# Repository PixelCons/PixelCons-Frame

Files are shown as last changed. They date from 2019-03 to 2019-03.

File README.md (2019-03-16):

# PixelCons-Frame
Pixel Art Showcase Frame

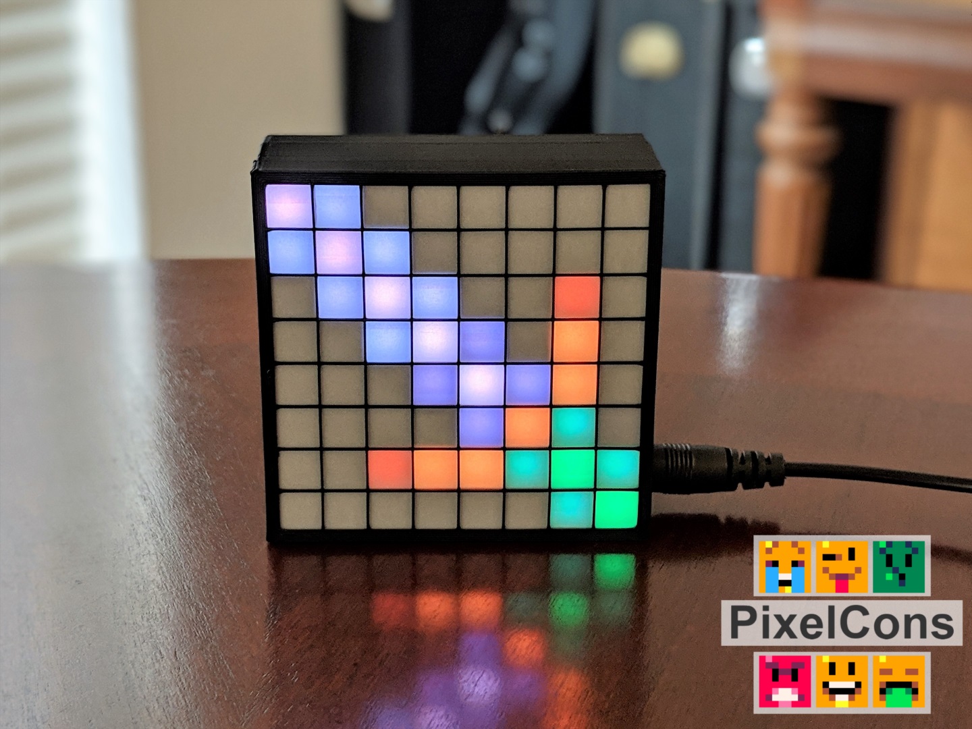
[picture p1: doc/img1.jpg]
Example


The PixelCon Frame is small device that displays pixel art (known as PixelCons) from the web. The pixel art is displayed on a bright 8x8 matrix of LEDs and is powered by the inexpensive WiFi enabled esp8266 board. Everything is enclosed in a 2.75in square 3D printed case.

Pixel art displayed on the frame comes from the PixelCon ecosystem on the Ethereum blockchain. Anyone can make and explore PixelCon and using the power of the Ethereum blockchain, each PixelCon can be owned, collected, and traded like a cryptocurrency.

Refer to the User Guide [here](https://github.com/PixelCons/PixelCons-Frame/blob/master/doc/PixelCon%20Frame%20(mini).pdf) for more information on using/setting up the PixelCon Frame once it's been assembled.

## Hardware
The PixelCon Frame consists of two main components, the NodeMCU ESP8266 microcontroller dev board and an 8x8 matrix of WS2812 LEDs. Other smaller passive components needed include an electrolytic capacitor, n-channel transistor and a single resistor.

- NodeMCU ESP8266 ([Amazon](https://www.amazon.com/NodeMCU-ESP8266-Internet-ESP-12E-Development/dp/B074Z2VL6S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))
- 8x8 WS2812 LEDs ([Amazon](https://www.amazon.com/Semoic-Matrix-WS2812-Full-Color-Arduino/dp/B07M6D5X34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))
- 5V 3A Power Supply ([Amazon](https://www.amazon.com/Bestcompu-Converter-Wireless-Switches-Video%EF%BC%885-5mm/dp/B00ME78NSS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))
- NPN Transistor
- DC Barrel Jack
- 8pin Female Headers (x2)
- 1000uF Capacitor
- 2.6kOhm Resistor

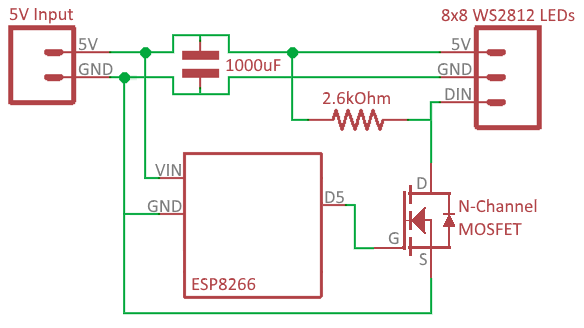
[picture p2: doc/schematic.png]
Schematic


## Software
All software for the PixelCon Frame is run on the ESP8266 microcontroller and was designed to use the Arduino IDE for flashing the code. To flash the code to the NodeMCU ESP8266 board, follow these steps:

1. Download and install the arduino IDE [here](https://www.arduino.cc/en/Main/Software).
2. Add the ESP8266 boards to the Arduino IDE by following this [tutorial](https://www.instructables.com/id/Programming-ESP8266-ESP-12E-NodeMCU-Using-Arduino-/).
3. Download the source code [here](https://codeload.github.com/PixelCons/PixelCons-Frame/zip/master) and unzip into a folder labeled ‘PixelCon-Frame’. 
4. Add the WiFi Manager library development branch to the Arduino IDE by downloading it [here](https://codeload.github.com/tzapu/WiFiManager/zip/development) and unzip into a folder labeled ‘WiFiManager’ in the directory ‘Documents\Arduino\libraries’. 
5. Open the PixelCons-Frame.ino file in the Arduino IDE and click the ‘Verify’ button to make sure everything compiles successfully. Refer back to the earlier tutorial [here](https://www.instructables.com/id/Programming-ESP8266-ESP-12E-NodeMCU-Using-Arduino-/) for uploading the code to the ESP8266 on the NodeMCU dev board.

Packed inside of the code is the web interface for configuring the behavior of the PixelCon Frame. Refer to the User Guide [here](https://github.com/PixelCons/PixelCons-Frame/blob/master/doc/PixelCon%20Frame%20(mini).pdf) for an explanation of using the software.

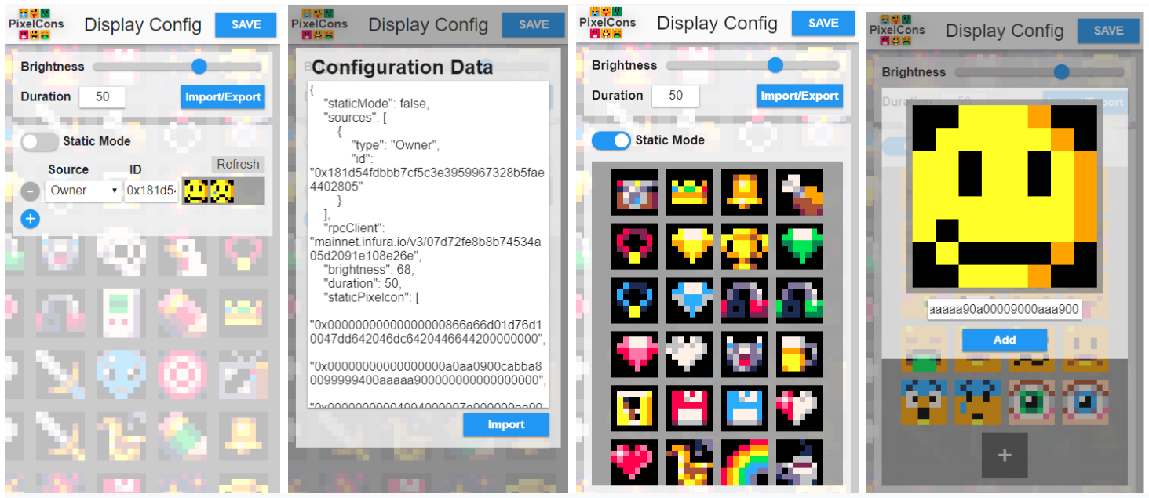
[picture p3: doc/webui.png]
WebUI


## Assembly
The PixelCon Frame body can be 3D printed from the STL files found [here](https://github.com/PixelCons/PixelCons-Frame/tree/master/stl) in the stl folder. To make your own, simply print them out and follow these assembly steps:

1. Place a cut piece of paper in between the 'frame' and the 'front' prints and snap in place.
2. The ESP8266 board should be screwed into into the 'backplate' with the 'buttons' in place. 
3. Super glue the 'bracket' onto the back of the LED matrix with all of the components in place. 
4. Wire and solder the correct components together according to the schematic.
5. Hot glue the LED matrix into the 'frame' so that the DC jack lines up with the hole in the 'frame'. 
6. Push the 'backplate' into place at the back of the 'frame', seating the ESP8266 pins into the female headers.

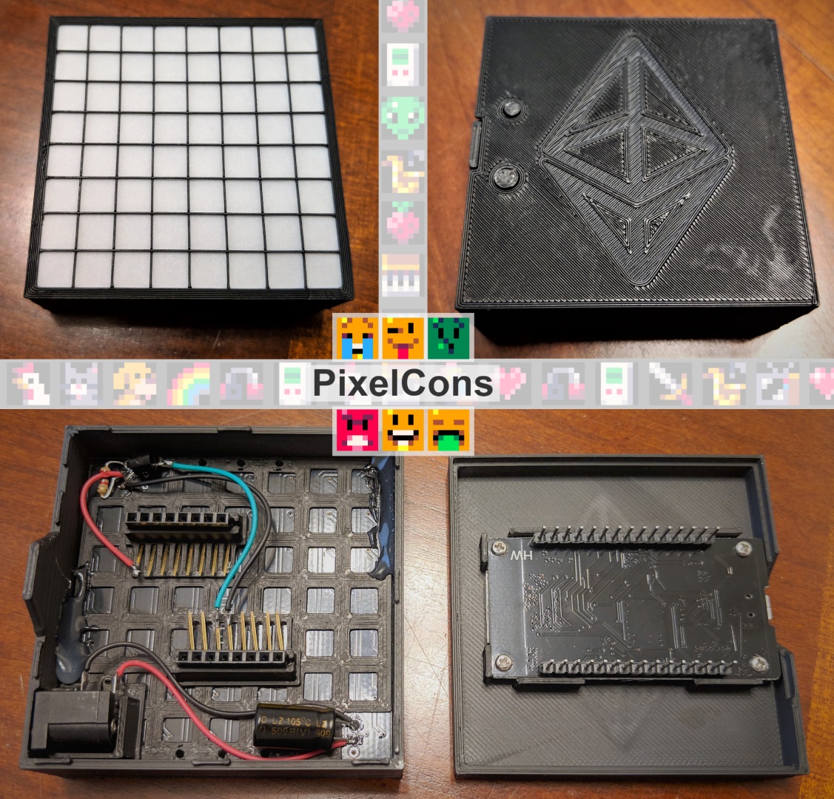
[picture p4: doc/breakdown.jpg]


## What's Next?
Currently, there is only the mini design, but it should be possible to create larger or even smaller versions and add features like an internal battery. Look forward to future software updates and more hardware revisions. 

Remember to check the User Guide [here](https://github.com/PixelCons/PixelCons-Frame/blob/master/doc/PixelCon%20Frame%20(mini).pdf) for more information on how to use the PixelCon Frame.

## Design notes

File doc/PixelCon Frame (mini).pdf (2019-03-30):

# PixelCon Frame (mini)

Mini Pixel Art Showcase Frame

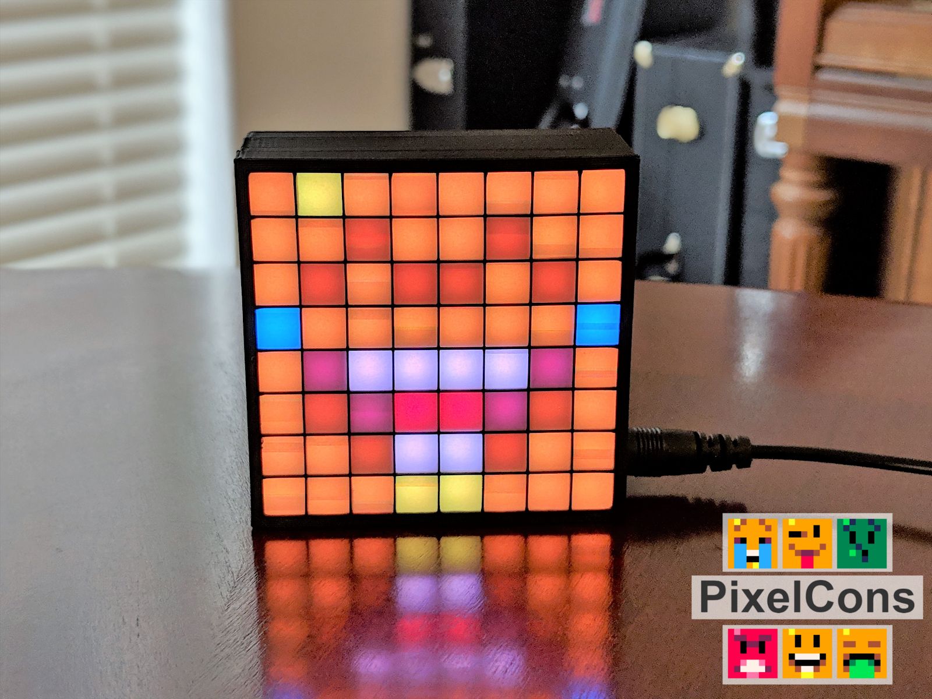
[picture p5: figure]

The PixelCon Frame is small device that displays pixel art (known as PixelCons) from the web. The pixel art is displayed on a bright 8x8 matrix of LEDs and is powered by the inexpensive WiFi enabled esp8266 board. Everything is enclosed in a 2.75in square 3D printed case.

Pixel art displayed on the frame comes from the PixelCon ecosystem on the Ethereum blockchain. Anyone can make and explore PixelCon and using the power of the Ethereum blockchain, each PixelCon can be owned, collected, and traded like a cryptocurrency.

How To...

### Connect to WiFi

The PixelCon Frame shows a stored set of PixelCon by default, but you can connect it to WiFi to display more PixelCon from the Ethereum blockchain. When the PixelCon Frame is not connected to WiFi, it acts as a WiFi hotspot (See Reset WiFi for clearing out any existing saved connection). Perform the following steps to set up a WiFi connection:
1. Connect to the PixelCon Frames WiFi hotspot through a computer of mobile device (the hotspot name will look like “PixelCon Frame xxxx”)
2. Navigate to the WiFi configuration page from your device (type in ‘192.168.244.1’ in a web browser if no prompt pops up)
3. Select a WiFi network, enter the password and click connect
4. If the configuration was correct, the PixelCon Frame will stop acting as a WiFi hotspot and will instead be connected to the configured WiFi network.

### Reset WiFi

The PixelCon Frame saves WiFi connection data for the next time it’s powered on. To clear out these settings and connect to a different WiFi network, perform the following steps:
1. Press and hold the bigger action button on the back of the frame until the screen turns off
2. Press the smaller reset button on the back of the frame to re-power the frame
3. On boot, the PixelCon Frame should now start up as a WiFi hotspot to set up a new WiFi connection (See Connect to WiFi for setup instructions)

### Configure Settings

There are several settings that can be tweaked for the PixelCon Frame from a web interface. To access these controls, perform the following steps:
1. Make sure your PixelCon frame is connected to WiFi and you have a second device with a web browser connected to the same WiFi network.
2. Press the bigger action button on the back of the frame to see its IP address scroll across the screen. (You may have to hold the button down for a second, but make sure to release it as soon as the IP address shows)
3. Enter the IP address in the browser of a device connected to the same WiFi network. (This should take you to the configuration web interface for the PixelCon Frame)

# Configuration Web Interface

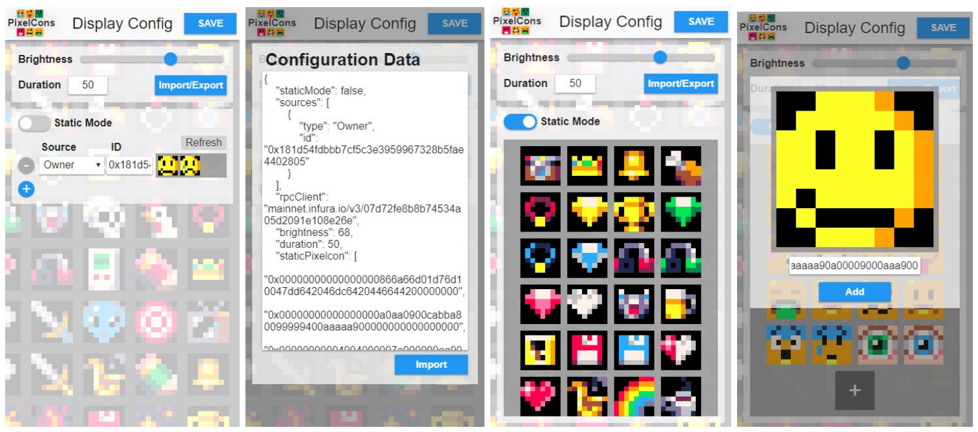
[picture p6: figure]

### General Settings

At the top of the page there is the general settings section. This section includes the brightness slider and duration input, which sets the number of seconds between the pixel art changing. Once these settings have been updated, click the Save button to update the PixelCon Frame.

### Import/Export

Also in the general settings section is a button for the import/export functionality. Clicking this button will bring up a window that displays the PixelCon Frames current configuration in a text box. Copy this text and save it somewhere to effectively export the current settings. Change the displayed text or paste in a previous configuration and click the Import button to load the configuration data. Once the data is loaded, click the Save button to update the PixelCon Frame to these settings.

### Dynamic Mode

The lower half of the page is for configuring what pixel art is shown. A toggle at the top of this section allows you to switch between a Static and Dynamic mode. Dynamic mode allows you to configure the PixelCon Frame to display PixelCon from different sources from the Ethereum blockchain (See here (https://pixelcons.io/) for more information on PixelCon). This data is updated in real time as transactions get committed to the blockchain.

Clicking the Plus button will add a source to the list, while clicking the Minus button will remove a source. Use the dropdown in the Source column to configure what type of source a line is. A source can be an artist address, an owner address, a collection index, or simply specify all PixelCon currently in existence. In the ID column, specify the artist/owner address or collection index. You can add up to 10 different sources, which will randomly be pulled from when displaying pixel art.

### Static Mode

Switching on the Static Mode toggle will switch the configuration into a static mode. In this mode, you can simply add and remove PixelCon that will be displayed. These configured PixelCon are also what the PixelCon Frame will display when it cannot connect to WiFi.

Clicking on a PixelCon icon will enable you to remove it from the list. Clicking the Plus button will open the add PixelCon window. In this window, there is a text box where you can enter a PixelCon ID (See here (https://pixelcons.io/) for more information on PixelCon). Click the Add button to then add the entered PixelCon to the list. Up to 100 individual PixelCon can be added to the static list, which will randomly be pulled from when displaying the pixel art.

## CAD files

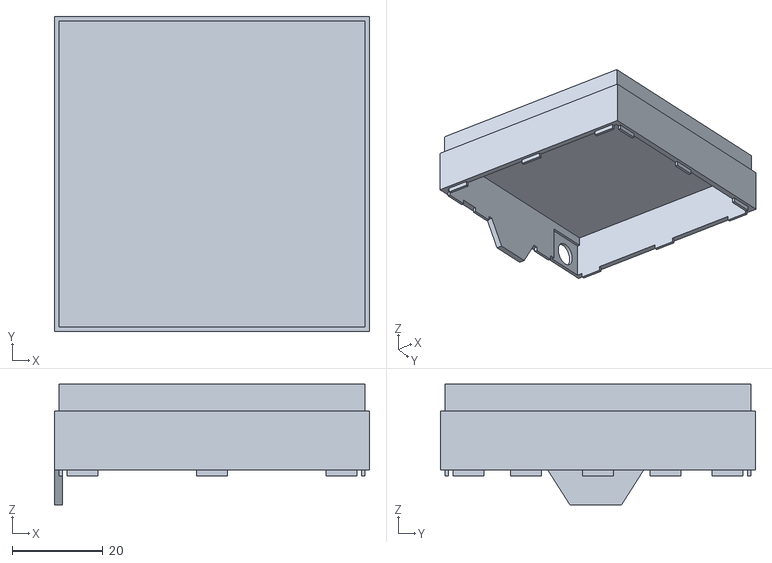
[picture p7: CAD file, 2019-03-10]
stl/pixelcon_frame.stl
69.6 x 69.6 x 26.7

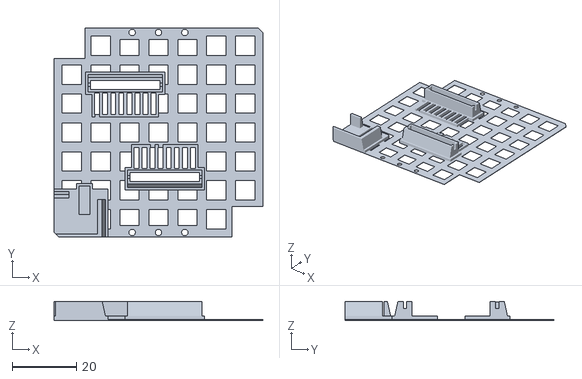
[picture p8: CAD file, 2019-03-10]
stl/pixelcon_bracket.stl
65.0 x 65.0 x 5.95

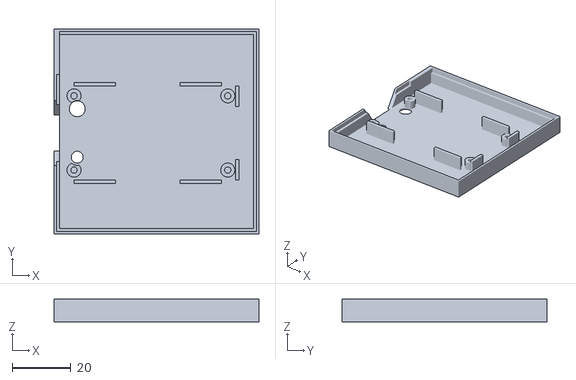
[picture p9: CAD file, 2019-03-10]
stl/pixelcon_backplate.stl
69.6 x 69.6 x 7.70

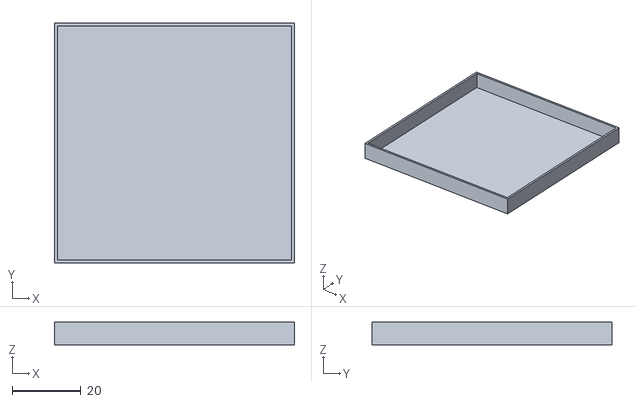
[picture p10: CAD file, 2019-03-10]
stl/pixelcon_front.stl
69.6 x 69.6 x 6.60

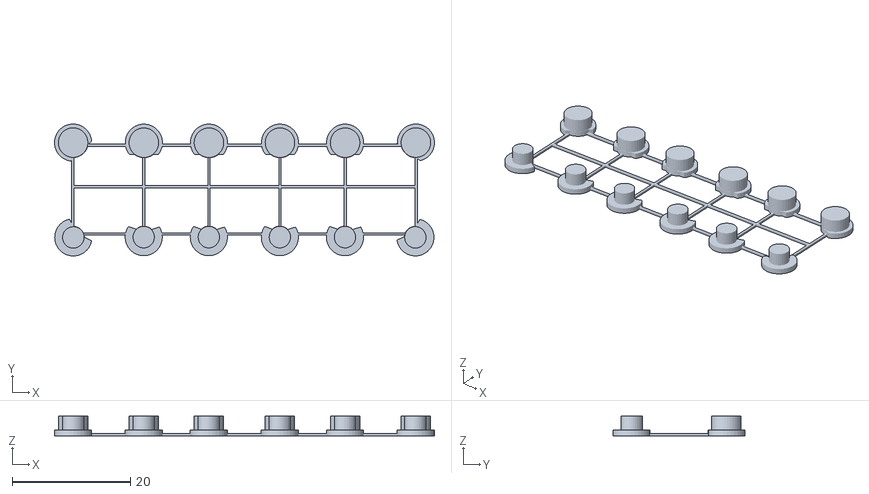
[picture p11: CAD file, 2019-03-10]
stl/pixelcon_buttons.stl
64.2 x 22.3 x 3.30

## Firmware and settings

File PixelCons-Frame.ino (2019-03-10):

#include <ESP8266WiFi.h>
#include "src/utils.h"
#include "src/storage.h"
#include "src/ethereum.h"
#include "src/display.h"
#include "src/network.h"

#include "src/rendering.h"
#include "src/pageConfig.h"

// Setup
void setup() {
  pinMode(0, INPUT);
  Serial.begin(115200);
  Serial.println("PixelCon Frame v1.0");
  Serial.println();
  storage::init();
  display::init();
  
  rendering::init();
  pageConfig::setup();

  display::drawLoadingScreen();
  display::flush();

  network::connect();
  if(network::isWifiSaved()) {
    if(network::checkConnection()) {
      rendering::setWiFiRenderMode(true);
    } else {
      if(!storage::getIsStaticMode()) {
        display::drawErrorScreen();
        display::flush();
        delay(5000);
      }
    }
  }
}

// Loop
int buttonHold = 0;
void loop() {
  bool wifiConnected = network::checkConnection();

  // run render routine
  rendering::process(wifiConnected);

  // check for button press
  if(digitalRead(0) == LOW) {
    buttonHold++;
    rendering::showIPAddress();
  } else buttonHold = 0;

  // check for wifi reset
  if(buttonHold > 100000) {
    network::resetWifi();
    display::drawBlankScreen();
    display::flush();
    
    // loop forever until user resets
    Serial.println(FS("Please reset device"));
    while(true) delay(100);
  }
}

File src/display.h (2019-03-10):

#ifndef DISPLAY_H
#define DISPLAY_H
	
#include <Arduino.h>
#include <eagle_soc.h>
#include "utils.h"
#include "storage.h"

#define DISPLAY_WIDTH 8
#define DISPLAY_HEIGHT 8
#define DISPLAY_NUM_LEDS (DISPLAY_WIDTH*DISPLAY_HEIGHT)
#define DISPLAY_OUTPUT_PIN 14 //PIN D5
	
namespace display
{
	//////////////////////////////////////////////////////////////////////////////////////////////////////////////////////////
	///////////////////////////////////////////////////  Interface  //////////////////////////////////////////////////////////
	//////////////////////////////////////////////////////////////////////////////////////////////////////////////////////////
	void init();
	void flush();
	
	void drawErrorScreen();
	void drawLoadingScreen();
	void drawWarningScreen();
	void drawBlankScreen();
	
	void drawPixelcon(const char* id, int xOffset, int yOffset);
	void drawText(const char* text, int xOffset, int yOffset);
	
	void setColor(int x, int y, uint32_t color);
	void setColor(int x, int y, int r, int g, int b);
		
	/* Helper Functions */
	uint32_t colors(char index);
	void dimAt(int x, int y);
	void lightAt(int x, int y);
	extern "C" void ICACHE_RAM_ATTR espShow(uint8_t *pixels, uint32_t numBytes);
	
	
	/////////////////////////////////////////////////////////////////////////////////////////////////////////////////////
	///////////////////////////////////////////////////  Data  //////////////////////////////////////////////////////////
	/////////////////////////////////////////////////////////////////////////////////////////////////////////////////////
	uint8_t pixels[DISPLAY_NUM_LEDS*3];
	const char fontSegments[] PROGMEM = {0,1,1,3,5,7,9,11,11,12,13,15,17,18,20,20,22,24,24,26,28,30,32,34,36,38,40,40,41,43,45,47,49,51,53,55,57,59,61,63,65,67,69,71,73,75,77,79,81,83,85,87,89,91,93,95,97,99,
		101,103,104,106,107,109,111,112,114,116,118,120,122,124,126,128,128,129,131,131,133,135,137,139,141,142,143,145,147,149,151,153,155,157,159,159,161,163};
	const char fontData[] PROGMEM = {0x00,0x00,0x1d,0x18,0x00,0x18,0x1f,0x0a,0x1f,0x0d,0x1f,0x16,0x13,0x04,0x19,0x0a,0x15,0x0b,0x18,0x0e,0x11,0x11,0x0e,0x14,0x08,0x14,0x04,0x0e,0x04,0x01,0x02,0x04,0x04,0x04,0x01,
		0x01,0x06,0x18,0x1f,0x11,0x1f,0x1f,0x17,0x15,0x1d,0x15,0x15,0x1f,0x1c,0x04,0x1f,0x1d,0x15,0x17,0x1f,0x15,0x17,0x10,0x10,0x1f,0x1f,0x15,0x1f,0x1d,0x15,0x1f,0x0a,0x01,0x0a,0x04,0x0a,0x11,0x0a,0x0a,0x0a,0x11,
		0x0a,0x04,0x08,0x13,0x0c,0x0e,0x15,0x0d,0x0f,0x14,0x0f,0x1f,0x15,0x0a,0x0e,0x11,0x0a,0x1f,0x11,0x0e,0x1f,0x15,0x11,0x1f,0x14,0x10,0x0e,0x11,0x16,0x1f,0x04,0x1f,0x11,0x1f,0x11,0x11,0x1f,0x10,0x1f,0x04,0x1b,
		0x1f,0x01,0x01,0x1f,0x08,0x1f,0x1f,0x0e,0x1f,0x0e,0x11,0x0e,0x1f,0x14,0x08,0x0c,0x12,0x0d,0x1f,0x14,0x0b,0x09,0x15,0x12,0x10,0x1f,0x10,0x1e,0x01,0x1e,0x1c,0x03,0x1c,0x1e,0x07,0x1e,0x1b,0x04,0x1b,0x18,0x07,
		0x18,0x13,0x15,0x19,0x1f,0x11,0x18,0x06,0x01,0x11,0x1f,0x08,0x10,0x08,0x01,0x01,0x01,0x10,0x08,0x06,0x09,0x07,0x1f,0x09,0x06,0x06,0x09,0x09,0x06,0x09,0x1f,0x06,0x0b,0x05,0x04,0x1f,0x14,0x05,0x0b,0x06,0x1f,
		0x04,0x03,0x17,0x01,0x16,0x1f,0x02,0x05,0x1f,0x0f,0x0c,0x0f,0x07,0x08,0x07,0x06,0x09,0x06,0x0f,0x0a,0x04,0x04,0x0a,0x0f,0x0f,0x04,0x05,0x0a,0x04,0x0f,0x04,0x0e,0x01,0x0e,0x0c,0x03,0x0c,0x0e,0x03,0x0e,0x09,
		0x06,0x09,0x0d,0x03,0x0e,0x0b,0x0f,0x0d,0x04,0x1f,0x11,0x1f,0x11,0x1f,0x04,0x06,0x04,0x0c};
	const char warningScreen[] PROGMEM = {0x0e,0x07,0x00,0x35,0x1c,0x00,0xd8,0xd1,0xc9,0xd9,0xd1,0xc9,0xd9,0xd1,0xc9,0xd8,0xd1,0xc9,0x35,0x1c,0x00,0x10,0x08,0x00,0x35,0x1c,0x00,0x60,0x36,0x00,0xe1,0xd8,0xc9,0xe2,
		0xd9,0xc9,0xe2,0xd9,0xc9,0xe1,0xd8,0xc9,0x60,0x36,0x00,0x36,0x1d,0x00,0x4a,0x27,0x00,0x74,0x49,0x00,0x86,0x5c,0x03,0x8a,0x61,0x09,0xe6,0xdd,0xca,0xe5,0xdc,0xc9,0x75,0x49,0x00,0x4c,0x29,0x00,0x4f,0x2a,0x00,
		0x78,0x4d,0x00,0x8a,0x61,0x09,0xe6,0xde,0xcc,0xe6,0xde,0xcc,0xe6,0xdd,0xcb,0x79,0x4e,0x00,0x51,0x2b,0x00,0x4f,0x2a,0x00,0x78,0x4d,0x00,0x8a,0x61,0x09,0xe6,0xde,0xcc,0xe6,0xde,0xcc,0x8b,0x62,0x0b,0x79,0x4e,
		0x00,0x51,0x2b,0x00,0x4a,0x27,0x00,0x74,0x49,0x00,0x86,0x5c,0x03,0x8b,0x62,0x0b,0x8b,0x62,0x0b,0x87,0x5e,0x04,0x75,0x49,0x00,0x4c,0x29,0x00,0x35,0x1c,0x00,0x60,0x36,0x00,0x75,0x49,0x00,0xe2,0xd9,0xc9,0xe2,
		0xd9,0xc9,0x75,0x49,0x00,0x62,0x38,0x00,0x37,0x1d,0x00,0x10,0x08,0x00,0x36,0x1d,0x00,0x4c,0x29,0x00,0xda,0xd2,0xc9,0xda,0xd2,0xc9,0x4c,0x29,0x00,0x37,0x1d,0x00,0x11,0x08,0x00};
	const char errorScreen[] PROGMEM = {0x11,0x00,0x00,0x3f,0x00,0x00,0x59,0x00,0x00,0x5f,0x00,0x00,0x5f,0x00,0x00,0x59,0x00,0x00,0x40,0x00,0x00,0x13,0x00,0x00,0x3f,0x00,0x00,0x72,0x00,0x00,0x86,0x12,0x12,0xe6,
		0xcd,0xcd,0xe6,0xcd,0xcd,0x86,0x12,0x12,0x72,0x00,0x00,0x41,0x00,0x00,0x59,0x00,0x00,0x86,0x12,0x12,0x95,0x2b,0x2b,0xe9,0xd3,0xd3,0xe9,0xd3,0xd3,0x95,0x2b,0x2b,0x86,0x12,0x12,0x5b,0x00,0x00,0x5f,0x00,0x00,
		0x8a,0x16,0x16,0x98,0x31,0x31,0xe9,0xd4,0xd4,0xe9,0xd4,0xd4,0x98,0x32,0x32,0x8b,0x18,0x18,0x62,0x00,0x00,0x5f,0x00,0x00,0x8a,0x16,0x16,0x98,0x31,0x31,0xe9,0xd4,0xd4,0xe9,0xd4,0xd4,0x98,0x32,0x32,0x8b,0x18,
		0x18,0x62,0x00,0x00,0x59,0x00,0x00,0x86,0x12,0x12,0x95,0x2b,0x2b,0x98,0x32,0x32,0x98,0x32,0x32,0x96,0x2c,0x2c,0x86,0x12,0x12,0x5b,0x00,0x00,0x40,0x00,0x00,0x72,0x00,0x00,0x86,0x12,0x12,0xe6,0xce,0xce,0xe6,
		0xce,0xce,0x86,0x12,0x12,0x74,0x00,0x00,0x42,0x00,0x00,0x13,0x00,0x00,0x41,0x00,0x00,0x5b,0x00,0x00,0xdd,0xc9,0xc9,0xdd,0xc9,0xc9,0x5b,0x00,0x00,0x42,0x00,0x00,0x15,0x00,0x00};

	
	/////////////////////////////////////////////////////////////////////////////////////////////////////////////////////
	///////////////////////////////////////////////////  Impl  //////////////////////////////////////////////////////////
	/////////////////////////////////////////////////////////////////////////////////////////////////////////////////////
	void init() {
      pinMode(DISPLAY_OUTPUT_PIN, OUTPUT);
      digitalWrite(DISPLAY_OUTPUT_PIN, HIGH);
	  
	  for(int i=0; i<DISPLAY_NUM_LEDS*3; i++) pixels[i] = 0;
	}
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
